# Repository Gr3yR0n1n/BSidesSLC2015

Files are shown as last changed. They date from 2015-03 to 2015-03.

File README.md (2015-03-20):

# BSidesSLC 2015 Electronic Badge
[BSidesSLC](https://www.bsidesslc.org/), [theTransistor](http://thetransistor.com/), [DC801](https://www.dc801.org/), and [801 Labs](https://www.801labs.org/) brings you another fun conference badge.

**NOTE: The displays used in these badges are no longer being produced. They come from left over Nokia5110 units produced in China MANY years ago. Some of them have trouble working correctly. If you have this problem, we suggest gently pressing on the bottom of the LCDs metal frame. This sometimes helps reseat the internal display connector.**

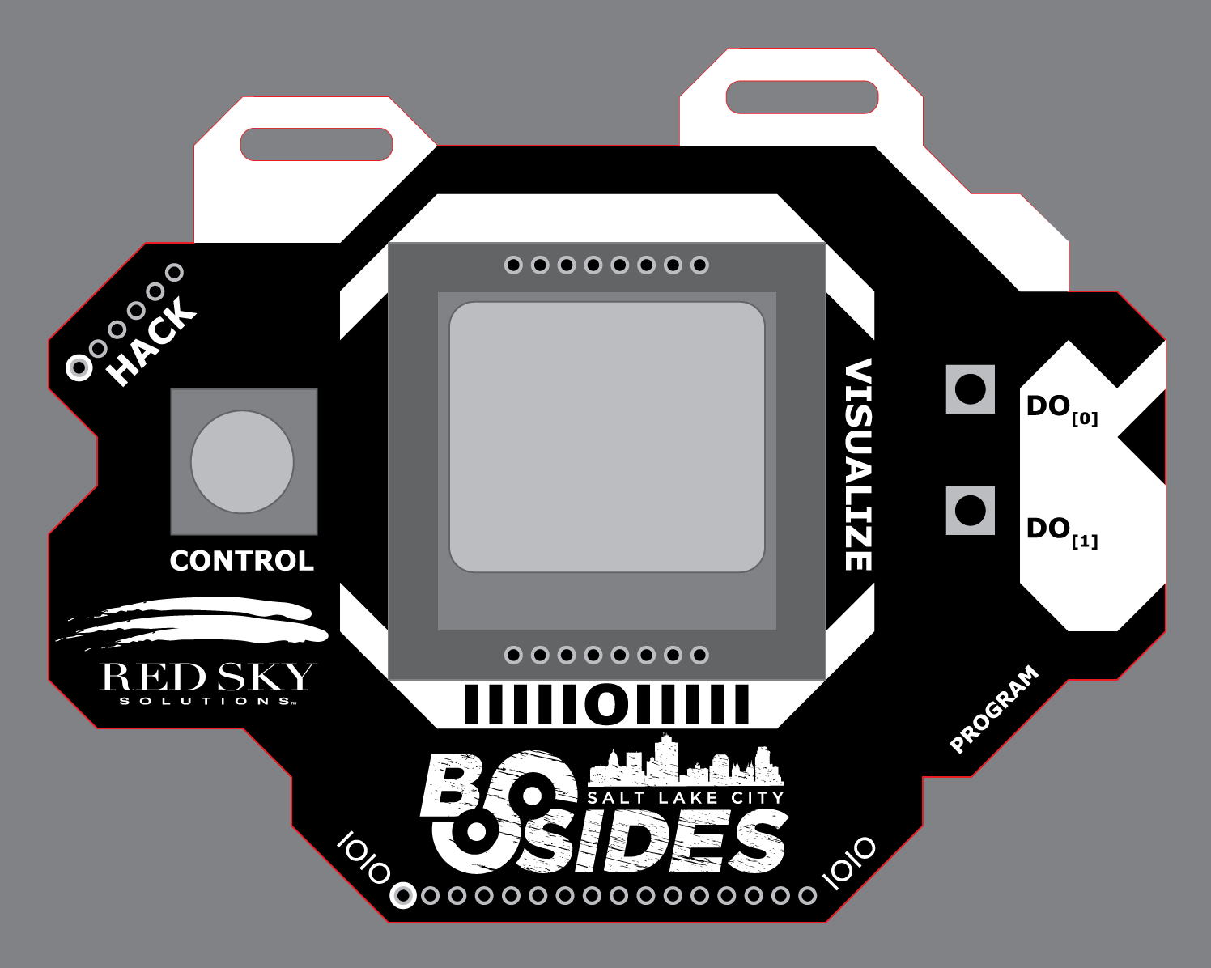
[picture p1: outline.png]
BSidesSLC 2015 Badge


##QuickSpecs
- Arduino bootloaded.
  - Any Atmega32u4 8mhz 3.3v bootloader will do.
  - We used the [Spark Fun Pro-Micro Bootloader and Arduino Hardware Files](https://www.sparkfun.com/products/12587)
- Atmel 32u4 mCU running at 8mhz on 3.3v
- Nokia 5110 LCD Display
  - 84px wide x 48px tall
  - Adjustable LED Backlight
  - Adjustable Contrast (via software)
- Controls
  - A (really) small 5 way Joypad
  - 2 Action Buttons
- Extra IO
  - Extra GPIO has been conveniently been broken-out on the bottom-edge of the board.
- Power
  - Selectable USB / 2x AAA Battery Power

##Reprogramming
Reprogramming can be done either over USB via the Arduino IDE, or over the serial "HACK" ISP breakout. To use the Arduino programming over USB, you will need to copy 8mhz Atmega32u4 hardware files into the "hardware" folder in your Arduino installation. See the SparkFun link above for more information.

##Credits:

**Electronics Work & Processing**
- Compukidmike
- Devino

**QA, Assembly, & Loading**
- l3mur (aka aarobc)
- Nemus
- Compukidmike
- Yukaia

**Original Design, Code, & Mgmt**
- D3c4f

**Special Thanks**
- Nemus
- T4rkus & BSidesSLC

##Questions and Comments
Questions and comments can be directed twards the following forms of communication:
- \#dc801 on freenode
- d3c4f [at] thetransistor [dot] com

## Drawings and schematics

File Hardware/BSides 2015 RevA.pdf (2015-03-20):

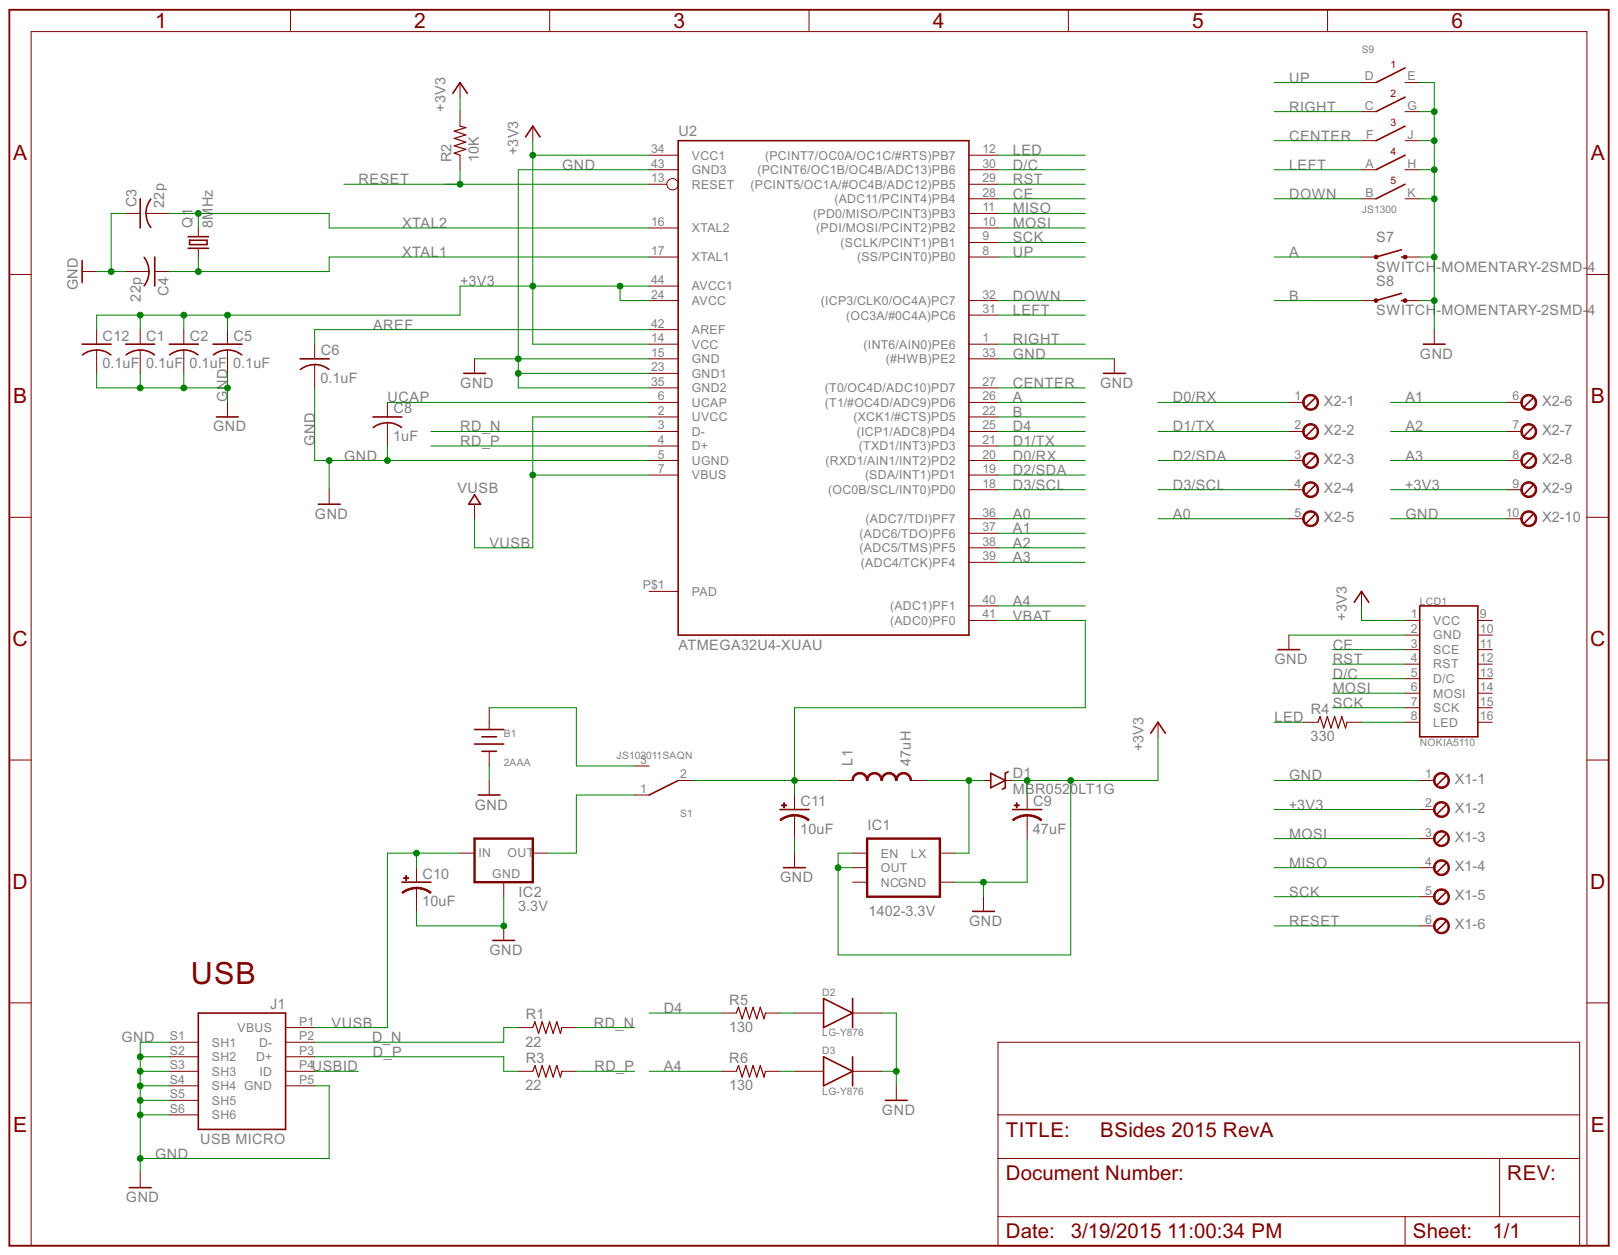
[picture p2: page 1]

LX GND OUT EN

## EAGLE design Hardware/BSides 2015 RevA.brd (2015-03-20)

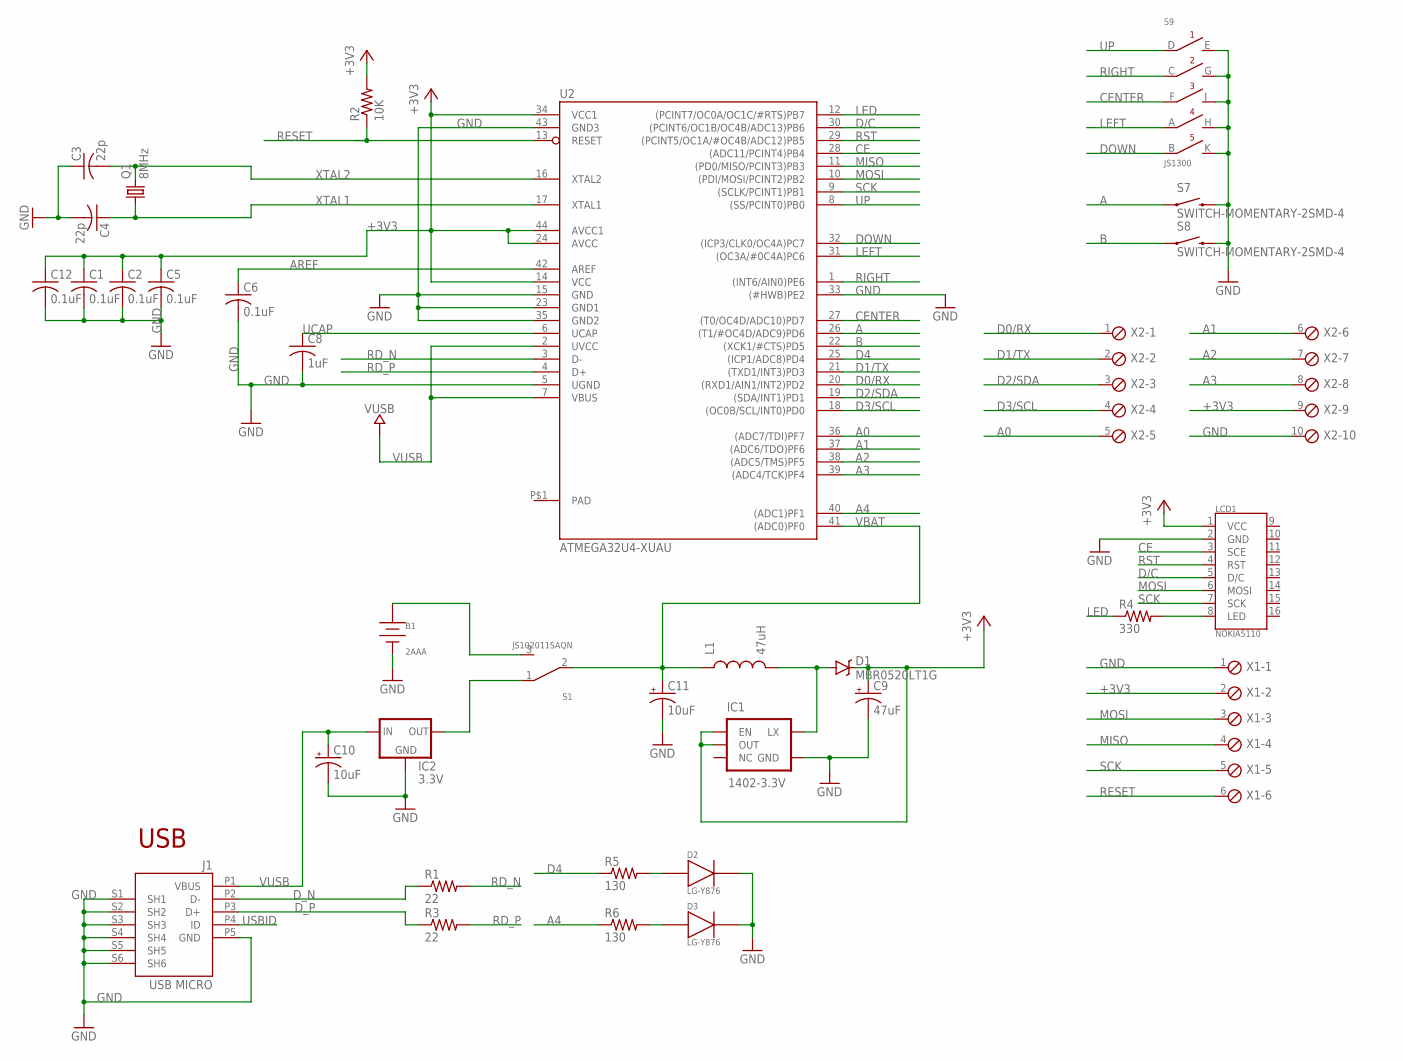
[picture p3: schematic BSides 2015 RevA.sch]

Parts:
B1: 2AAA
C1, C2, C5, C6, C12: 0.1uF; C0603K
C3, C4: 22p; C0603K
C8: 1uF; C0603K
C9: 47uF; 6032
C10, C11: 10uF; EIA3216
D1: MBR0520LT1G; SOD-123
D2, D3: LG-Y876
IC1: 1402-3.3V; SOT23-5
IC2: 3.3V; SOT23
J1: USB MICRO; CON2_USB_MICRO_B_AT
L1: 47uH; NR6028
LCD1: NOKIA5110; 5110
Q1: 8MHz; SM49
R1, R3: 22; R0603
R2: 10K; R0603
R4: 330; R0603
R5, R6: 130; R0603
S1: JS102011SAQN; SAQN
S7, S8: SWITCH-MOMENTARY-2SMD-4; TACTILE_SWITCH_TALL
S9: JS1300
U2: ATMEGA32U4-XUAU; TQFP44-PAD
X1: MPT6; 6POL254
X2: MPT10; 10POL254

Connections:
+3V3: C1.1, C2.1, C5.1, C9.P$2 (+), C12.1, D1.P$1 (C), IC1.1 (EN), IC1.2 (OUT), LCD1.1 (VCC), R2.2, U2.14 (VCC), U2.24 (AVCC), U2.34 (VCC1), U2.44 (AVCC1), X1.2, X2.9
A: S7.A2 (1), U2.26 ((T1/#OC4D/ADC9)PD6)
A0: U2.36 ((ADC7/TDI)PF7), X2.5
A1: U2.37 ((ADC6/TDO)PF6), X2.6
A2: U2.38 ((ADC5/TMS)PF5), X2.7
A3: U2.39 ((ADC4/TCK)PF4), X2.8
A4: R6.1, U2.40 ((ADC1)PF1)
AREF: C6.1, U2.42 (AREF)
B: S8.A2 (1), U2.22 ((XCK1/#CTS)PD5)
CE: LCD1.3 (SCE), U2.28 ((ADC11/PCINT4)PB4)
CENTER: S9.F, U2.27 ((T0/OC4D/ADC10)PD7)
D0/RX: U2.20 ((RXD1/AIN1/INT2)PD2), X2.1
D1/TX: U2.21 ((TXD1/INT3)PD3), X2.2
D2/SDA: U2.19 ((SDA/INT1)PD1), X2.3
D3/SCL: U2.18 ((OC0B/SCL/INT0)PD0), X2.4
D4: R5.1, U2.25 ((ICP1/ADC8)PD4)
D/C: LCD1.5 (D/C), U2.30 ((PCINT6/OC1B/OC4B/ADC13)PB6)
DOWN: S9.B, U2.32 ((ICP3/CLK0/OC4A)PC7)
D_N: J1.P2 (D-), R1.1
D_P: J1.P3 (D+), R3.1
GND: B1.-, C1.2, C2.2, C3.1, C4.2, C5.2, C6.2, C8.2, C9.P$1 (-), C10.C (-), C11.C (-), C12.2, D2.C, D3.C, IC1.4 (GND), IC2.1 (GND), J1.P5 (GND), J1.S1 (SH1), J1.S2 (SH2), J1.S3 (SH3), J1.S4 (SH4), J1.S5 (SH5), J1.S6 (SH6), LCD1.2 (GND), S7.B2 (2), S8.B2 (2), S9.E, S9.G, S9.H, S9.J, S9.K, U2.5 (UGND), U2.15 (GND), U2.23 (GND1), U2.33 ((#HWB)PE2), U2.35 (GND2), U2.43 (GND3), X1.1, X2.10
LED: R4.1, U2.12 ((PCINT7/OC0A/OC1C/#RTS)PB7)
LEFT: S9.A, U2.31 ((OC3A/#0C4A)PC6)
MISO: U2.11 ((PD0/MISO/PCINT3)PB3), X1.4
MOSI: LCD1.6 (MOSI), U2.10 ((PDI/MOSI/PCINT2)PB2), X1.3
unnamed: D1.P$2 (A), IC1.5 (LX), L1.P$2 (2)
unnamed: IC2.2 (OUT), S1.1
unnamed: B1.+, S1.3
unnamed: LCD1.8 (LED), R4.2
unnamed: D2.A, R5.2
unnamed: D3.A, R6.2
PAD: U2.P$1 (PAD)
RD_N: R1.2, U2.3 (D-)
RD_P: R3.2, U2.4 (D+)
RESET: R2.1, U2.13 (RESET), X1.6
RIGHT: S9.C, U2.1 ((INT6/AIN0)PE6)
RST: LCD1.4 (RST), U2.29 ((PCINT5/OC1A/#OC4B/ADC12)PB5)
SCK: LCD1.7 (SCK), U2.9 ((SCLK/PCINT1)PB1), X1.5
UCAP: C8.1, U2.6 (UCAP)
UP: S9.D, U2.8 ((SS/PCINT0)PB0)
USBID: J1.P4 (ID)
VBAT: C11.A (+), L1.P$1 (1), S1.2, U2.41 ((ADC0)PF0)
VUSB: C10.A (+), IC2.3 (IN), J1.P1 (VBUS), U2.2 (UVCC), U2.7 (VBUS)
XTAL1: C4.1, Q1.1, U2.17 (XTAL1)
XTAL2: C3.2, Q1.2, U2.16 (XTAL2)

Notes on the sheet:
USB

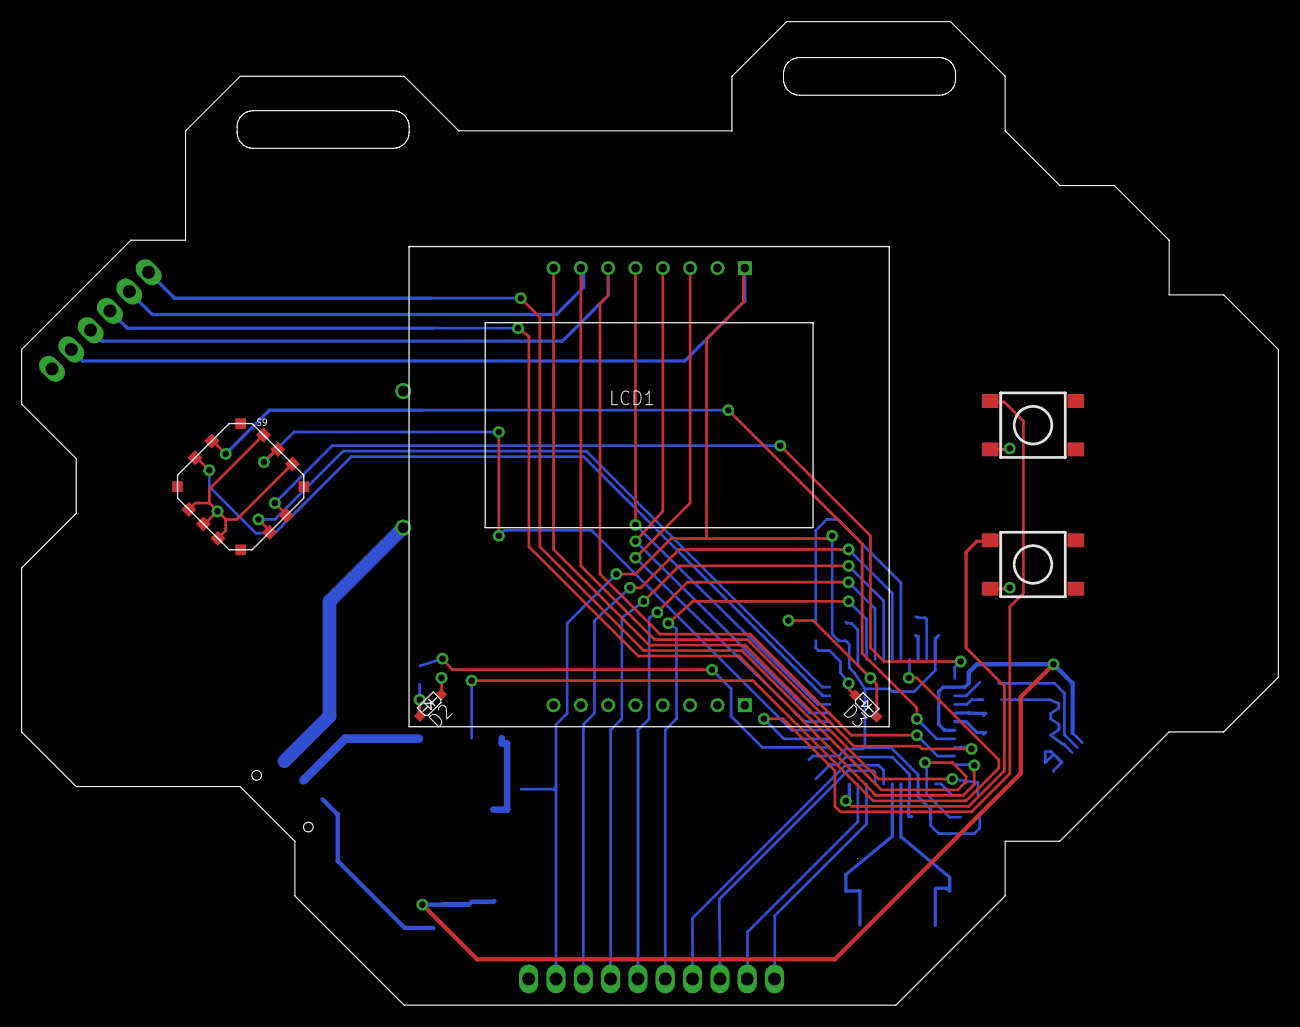
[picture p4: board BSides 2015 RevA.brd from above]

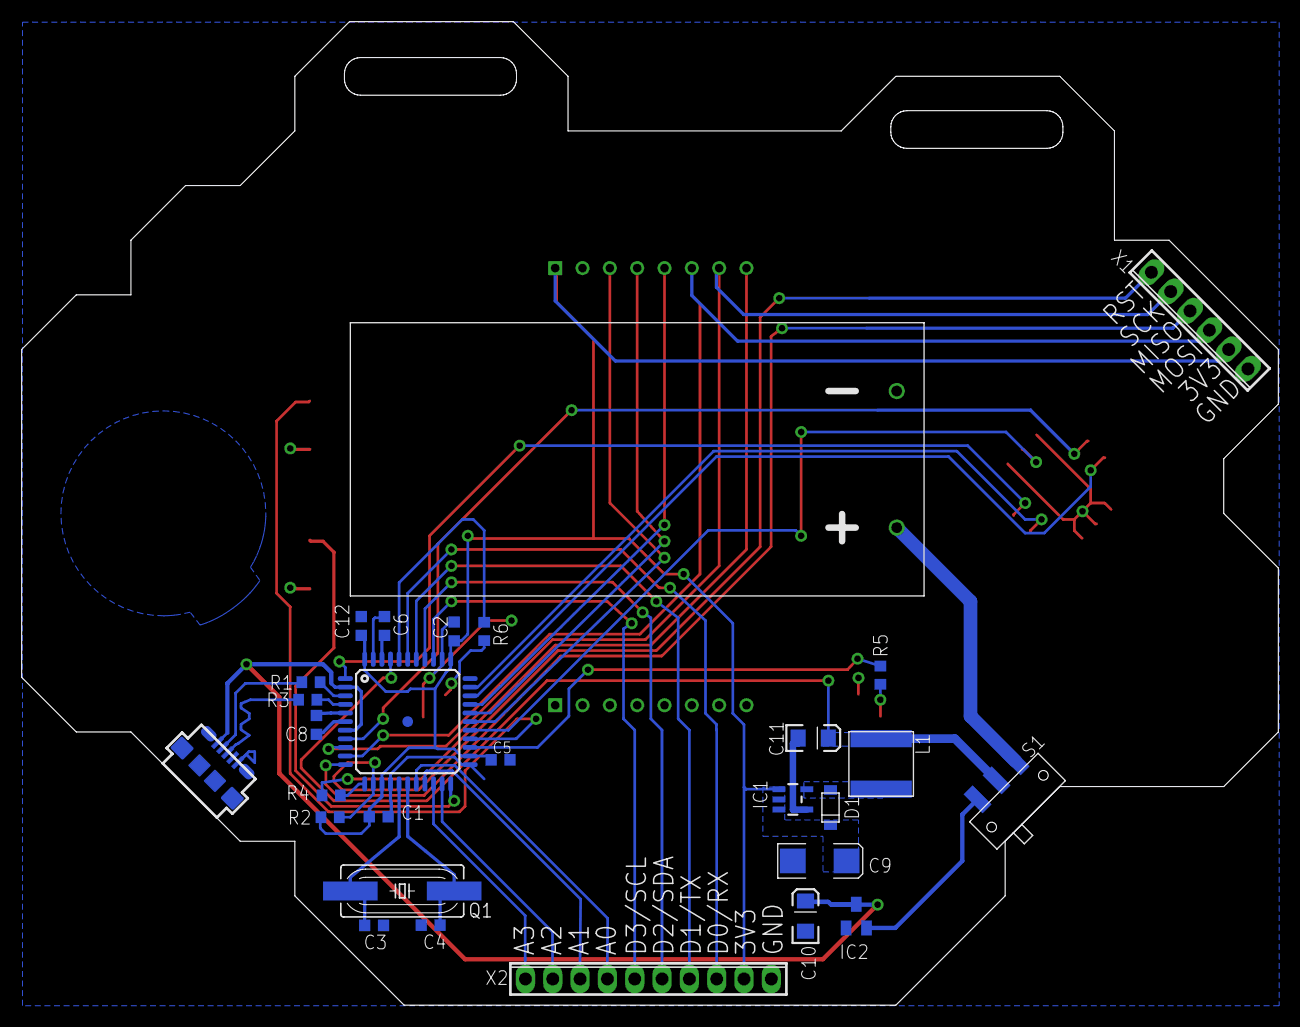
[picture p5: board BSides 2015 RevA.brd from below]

Board: 4 copper layers, 116.8 x 91.4 mm, 34 parts (28 on the bottom side), 43 nets.

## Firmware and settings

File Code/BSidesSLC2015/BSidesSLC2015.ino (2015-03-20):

/*
    theTransistor, DC801, and 801 Labs brings you another fun conference badge. :)
    
    Credits go out to:
    
    ++ Electronics Work & Processing
    + Compukidmike
    + Devino
    
    ++ QA, Assembly, & Loading
    + l3mur (aka aarobc)
    + Yukaia
    + Compukidmike
    
    ++ Original Design, Code, & Mgmt
    + D3c4f
    
    ++ Special Thanks
    + Nemus
    + T4rkus & BSidesSLC
    
    Questions and comments can be directed twards the following forms of communication:
    #dc801 on freenode
    d3c4f@thetransistor.com
*/

#include "Arduino.h"
#include "badge.h"
#include "lcd5110.h"
#include "bitmaps.h"
#include <avr/pgmspace.h>
#include <EEPROM.h>

Badge badge;    // Welcome to Arduino... :S
LCD5110 display;
bool ShowMenu = true; // Super basic menu support
bool Menu1 = true;


void setup(void) {
	display.DisplayBitmap(BSidesSLC);
	delay(1000);
    BSidesSLC_Animation();
}

// TODO: Update the menu "system"
void loop(void) {
    if (ShowMenu == true)
    {
        ShowMenu = false;
        if(Menu1)
        {
            display.DisplayBitmap_PROGMEM(Menu1_px);   
        }
        else
        {
            display.DisplayBitmap_PROGMEM(Menu2_px);
        }
        
        //display.Clear();
        //display.WriteString("a) BSidesLogo", 1, 30);
        //display.WriteString("b) NYAN", 1, 39);
        //display.Redraw();
    }
	
    if (badge.JoyUp(15, false) || badge.JoyDown(15, false))
    {
        if(Menu1) Menu1 = false;
        else Menu1 = true;
        ShowMenu = true;
    }
    
    if( badge.Button0(15, false) || badge.Button1(15, false))
    {
        if(Menu1) BSidesSLC_Animation();
        else NYAN_Animation();
        ShowMenu = true;
    }
    
}


// Animation routine for the BSidesSLC Logo
void NYAN_Animation(void)
{
    long delayTime = random(250,750);
    long lastUpdate = millis();
    uint8_t curFrame = 1;
    display.DisplayBitmap_PROGMEM(NYAN_frame1);
    
    while(!badge.Button0(50, false) && !badge.Button1(50, false) && !(badge.JoyUp(50, false)) && !(badge.JoyDown(50, false)))
    {
        if(millis() < lastUpdate) lastUpdate = millis(); // Edge case precaution
        
        if(millis() > lastUpdate + delayTime)
        {
            lastUpdate = millis();
            delayTime = random(250,750);
            
            if (curFrame <= 1)
            {
                display.DisplayBitmap_PROGMEM(NYAN_frame1);
                curFrame++;
            }
            else if (curFrame == 2)
            {
                display.DisplayBitmap_PROGMEM(NYAN_frame2);
                curFrame++;
            }
            else if (curFrame >= 3)
            {
                display.DisplayBitmap_PROGMEM(NYAN_frame3);
                curFrame = 1;
            }
        } 
    }
}


// Animation routine for NYAN Cat
void BSidesSLC_Animation(void)
{
    long delayTime = random(250,750);
    long lastUpdate = millis();
    display.DisplayBitmap(BSidesSLC);
	
    while(!badge.Button0(50, false) && !badge.Button1(50, false) && !(badge.JoyUp(50, false)) && !(badge.JoyDown(50, false)))
    {
        if(millis() < lastUpdate) lastUpdate = millis(); // Edge case precaution
        
        if(millis() > lastUpdate + delayTime)
        {
            lastUpdate = millis();
            delayTime = random(250,750);
            
            switch(random(12))
            {
                case 0:
                    display.TogglePixel(44,11);
                    break;
                case 1:
                    display.TogglePixel(43,13);
                    break;
                case 2:
                    display.TogglePixel(47,12);
                    break;
                case 3:
                    display.TogglePixel(49,11);
                    break;
                case 4:
                    display.TogglePixel(54,6);
                    break;
                case 5:
                    display.TogglePixel(54,8);
                    break;
                case 6:
                    display.TogglePixel(56,10);
                    break;
                case 7:
                    display.TogglePixel(57,8);
                    break;
                case 8:
                    display.TogglePixel(63,13);
                    break;
                case 9:
                    display.TogglePixel(67,12);
                    break;
                case 10:
                    display.TogglePixel(77,8);
                    break;
                case 11:
                    display.TogglePixel(77,9);
                    break;
                case 12:
                    display.TogglePixel(77,11);
                    break;
            }
            display.Redraw();
        } 
    }
}

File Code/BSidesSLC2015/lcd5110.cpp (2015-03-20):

/*
    Filename: lcd5110.cpp
    Purpose: Library for Nokia5110 LCD on the 2015 BSidesSLC Badge
    Created: March 16, 2013
    Original Author: d3c4f

    Original Credit: Nathan Seidle, Spark Fun Electronics 2011
    Original Credit URL: https://github.com/sparkfun/GraphicLCD_Nokia_5110
    (Thanks Nathan!)
*/

#include "Arduino.h"
#include "lcd5110.h"
#include "bitmaps.h"

/*
SCE      : PB4
RESET    : PB5
DC       : PB6
SDIN     : PB2
SCLK     : PB1
LED Back : Arduino Analog 11 (PWM)
*/


// Constructor
LCD5110::LCD5110()
{
    Init();
    
    SetBacklight(0x80); // Set initial backlight level
}


// Initialize the display.
// Sets the LCD to a known state, Sets up the command list, Contrast, etc.
void LCD5110::Init()
{
    // Set display pins as outputs
    DDRB |= B11110110; // Set B7, B6, B5, B4, B2, B1 as outputs

    // Reset the LCD by toggling the reset pin
    PORTB &= B11011111; // Pull B5 Low
    PORTB |= B00100000; // Pull B5 High

    Write(LCD_COMMAND, 0x21); //Tell LCD that extended commands follow
    Write(LCD_COMMAND, 0xB3); //Set LCD Vop (Contrast): Try 0xB1(good @ 3.3V) or 0xBF if your display is too dark
    Write(LCD_COMMAND, 0x04); //Set Temp coefficient
    Write(LCD_COMMAND, 0x13); //LCD bias mode 1:48: Try 0x13 or 0x14

    Write(LCD_COMMAND, 0x20); //We must send 0x20 before modifying the display control mode
    Write(LCD_COMMAND, 0x0C); //Set display control, normal mode. 0x0D for inverse

    Clear();
}


// Change the backlight level
void LCD5110::SetBacklight(uint8_t level)
{
    // Could maybe switch this to direct port manipulation later...
    analogWrite(11, level);
}


// Set a pixel of the (84 x 48) display buffer
void LCD5110::SetPixel(uint16_t x, uint16_t y)
{
    if (x >= 84 || y >= 48) return; // Bounds check
    displayBuffer[(84 * (y / 8)) + x] |= (1 << (y % 8));
}


// Clear a pixel of the (84 x 48) display buffer
void LCD5110::ClearPixel(uint16_t x, uint16_t y)
{
    if (x >= 84 || y >= 48) return; // Bounds check
    displayBuffer[(84 * (y / 8)) + x] &= ~(1 << (y % 8));
}


// Toggle a pixel of the (84 x 48) display buffer
void LCD5110::TogglePixel(uint16_t x, uint16_t y)
{
    if (x >= 84 || y >= 48) return; // Bounds check
    displayBuffer[(84 * (y / 8)) + x] ^= (1 << (y % 8));
}


// Write a byte array to the display buffer and show it
void LCD5110::DisplayBitmap(const uint8_t bitmap_array[])
{
    for (uint16_t curByte = 0 ; curByte < 504 ; curByte++)
    {
        //Write(LCD_DATA, bitmap_array[index]);
        displayBuffer[curByte] = bitmap_array[curByte];
    }
    
    Redraw();
}


// Write a byte array stored in program (flash) memory to the display buffer and show it
void LCD5110::DisplayBitmap_PROGMEM(const uint8_t bitmap_array[])
{
    for (uint16_t curByte = 0 ; curByte < 504 ; curByte++)
    {
        //Write(LCD_DATA, bitmap_array[index]);
        displayBuffer[curByte] = pgm_read_byte_near(bitmap_array + curByte);
    }
    
    Redraw();
}


// Write a character to the display
// Pads each character with 1px on either side for readability
void LCD5110::WriteCharacter(const char character, uint16_t x, uint16_t y)
{
    for (uint8_t colByte = 0 ; colByte < 5 ; colByte++)
    {
        //0x20 is the ASCII character for Space (' '). The font table starts with this character
        if(ASCII[character - 0x20][colByte] & BIT0_SET) SetPixel(x + colByte, y);
        else ClearPixel(x + colByte, y);

        if(ASCII[character - 0x20][colByte] & BIT1_SET) SetPixel(x + colByte, y + 1);
        else ClearPixel(x + colByte, y + 1);

        if(ASCII[character - 0x20][colByte] & BIT2_SET) SetPixel(x + colByte, y + 2);
        else ClearPixel(x + colByte, y + 2);

        if(ASCII[character - 0x20][colByte] & BIT3_SET) SetPixel(x + colByte, y + 3);
        else ClearPixel(x + colByte, y + 3);

        if(ASCII[character - 0x20][colByte] & BIT4_SET) SetPixel(x + colByte, y + 4);
        else ClearPixel(x + colByte, y + 4);

        if(ASCII[character - 0x20][colByte] & BIT5_SET) SetPixel(x + colByte, y + 5);
        else ClearPixel(x + colByte, y + 5);

        if(ASCII[character - 0x20][colByte] & BIT6_SET) SetPixel(x + colByte, y + 6);
        else ClearPixel(x + colByte, y + 6);

        if(ASCII[character - 0x20][colByte] & BIT7_SET) SetPixel(x + colByte, y + 7);
        else ClearPixel(x + colByte, y + 7);
        
        //Write(LCD_DATA, ASCII[character - 0x20][colByte]);
    }
}


// Writes an array of characters to a single line.
void LCD5110::WriteString(const char *characters, uint16_t x, uint16_t y)
{
    uint8_t curChar = 0;
    while (*characters)
    {
        WriteCharacter(*characters++, x + (curChar * 6), y);
        curChar ++;
    }
}


// Zero out the entire display buffer and redraw
void LCD5110::Clear()
{
    for (uint16_t curByte = 0 ; curByte < 504 ; curByte++)
    {
        displayBuffer[curByte] = 0x00;
    }
    Redraw();
}


// Change the contrast: try 0xB1 to 0xB3
//void SetContrast(uint8_t cont);


// Change the display bias mode: try 0x13 or 0x14
//void SetBias(uint8_t bias);


// Move to X,Y position
void LCD5110::GotoXY(uint8_t x, uint8_t y)
{
        Write(LCD_COMMAND, 0x80 | x);  // Column.
        Write(LCD_COMMAND, 0x40 | y);  // Row.  ?
}
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

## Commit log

2015-03-20 Initial commit
    Now with actual files! :)
    [BSides 2015 RevA.brd, BSides 2015 RevA.sch]
2015-03-20 Move Arduino files for make Arduino IDE easier to work with.

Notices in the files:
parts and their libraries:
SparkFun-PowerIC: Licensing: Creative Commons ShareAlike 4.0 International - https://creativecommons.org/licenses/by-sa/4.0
